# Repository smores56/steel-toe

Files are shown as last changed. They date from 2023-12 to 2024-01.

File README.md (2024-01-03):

The Steel Toe
=============

The Steel Toe is a 34-key split keyboard. It has the following features:

- Choc V1 switches (solder or hotswap)
- Wireless or wired only with any Pro Micro-compatible controller
- Pinky clusters (top pinky keys on the sides)
- Splay (4° between middle and ring, 8° between ring and pinky)
- SplitKB puck support for tenting

<!-- TODO: update pics -->
both sides of PCB

## How to Order

The [gerber ZIP](./pcb/production/gerber.zip) has everything you'll need to get this printed.
You can order from [JLC](https://jlcpcb.com) by just uploading that ZIP archive and keeping
the default options. I'd suggest removing the order number, otherwise they'll put
one on the board somewhere randomly.

## Building

### Parts Needed

Part Name            | Quantity        | Notes                                    | Link
--------------------:|:---------------:|:----------------------------------------:|:----
PCB                  | 2 (halves)      |                                          | Look up hurr hurr
Choc V1 Switches     | 34              |                                          | <https://www.boardsource.xyz/tags/LP_switch>
Choc Hotswaps        | 34              |                                          | <https://www.boardsource.xyz/products/Choc_Hot_Swap_Sockets>
Choc Keycaps         | 34              |                                          | <https://www.boardsource.xyz/tags/LP_keycaps>
Power Switches       | 2               | Technically optional                     | <https://www.boardsource.xyz/products/smd-slide-switch>
Reset Switches       | 2               | Technically optional                     | <https://www.boardsource.xyz/products/reset-switches>
Pro Micro Controller | 2               | Not technically optional                 | <https://www.boardsource.xyz/products/blok>
Small LiPo Batteries | 2               | Technically optional                     | <https://www.boardsource.xyz/products/110mAh_301230r>
MCU Sockets          | 1 strip to chop | Optional                                 | <https://www.boardsource.xyz/products/mill_max_sockets_set>
MCU Socket Pins      | 28              | Optional                                 | <https://www.boardsource.xyz/products/pins>

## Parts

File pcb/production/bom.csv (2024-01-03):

Designator | Footprint | Quantity | Value | LCSC Part #
+1, -1 | single-pin | 2 | MountingHole_Pad
J0 | trrs | 1 | AudioJack4dpb
SW1, SW10, SW11, SW12, SW13, SW14, SW15, SW16, SW17, SW2, SW3, SW4, SW5, SW6, SW7, SW8, SW9 | choc-switch-socket-only | 17 | SW_Push
SW18, SW21 | smd_rst_sw | 2 | SW_Push
SW19, SW20 | power-switch | 2 | SW_SPDT
U1 | ProMicro_facedown_new_dual | 1 | ProMicro_r

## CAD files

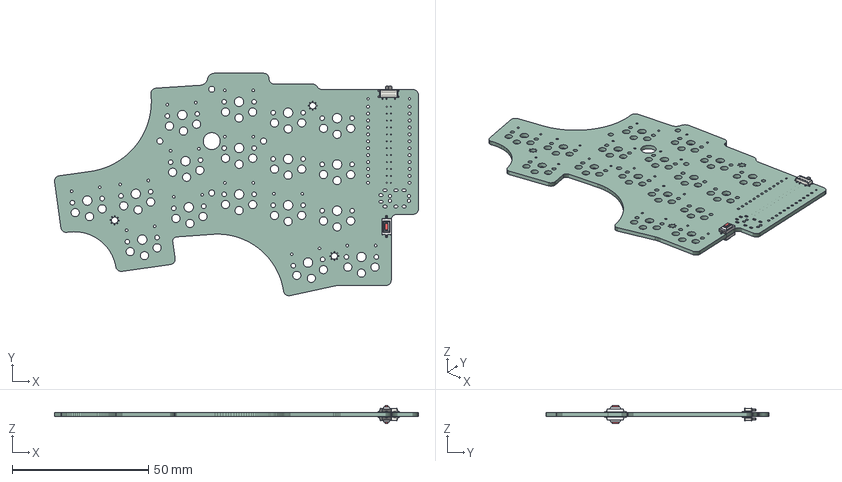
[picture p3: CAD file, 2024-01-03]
pcb/steel-toe.step
133.7 x 81.8 x 6.70 mm
_autosave-steel-toe PCB

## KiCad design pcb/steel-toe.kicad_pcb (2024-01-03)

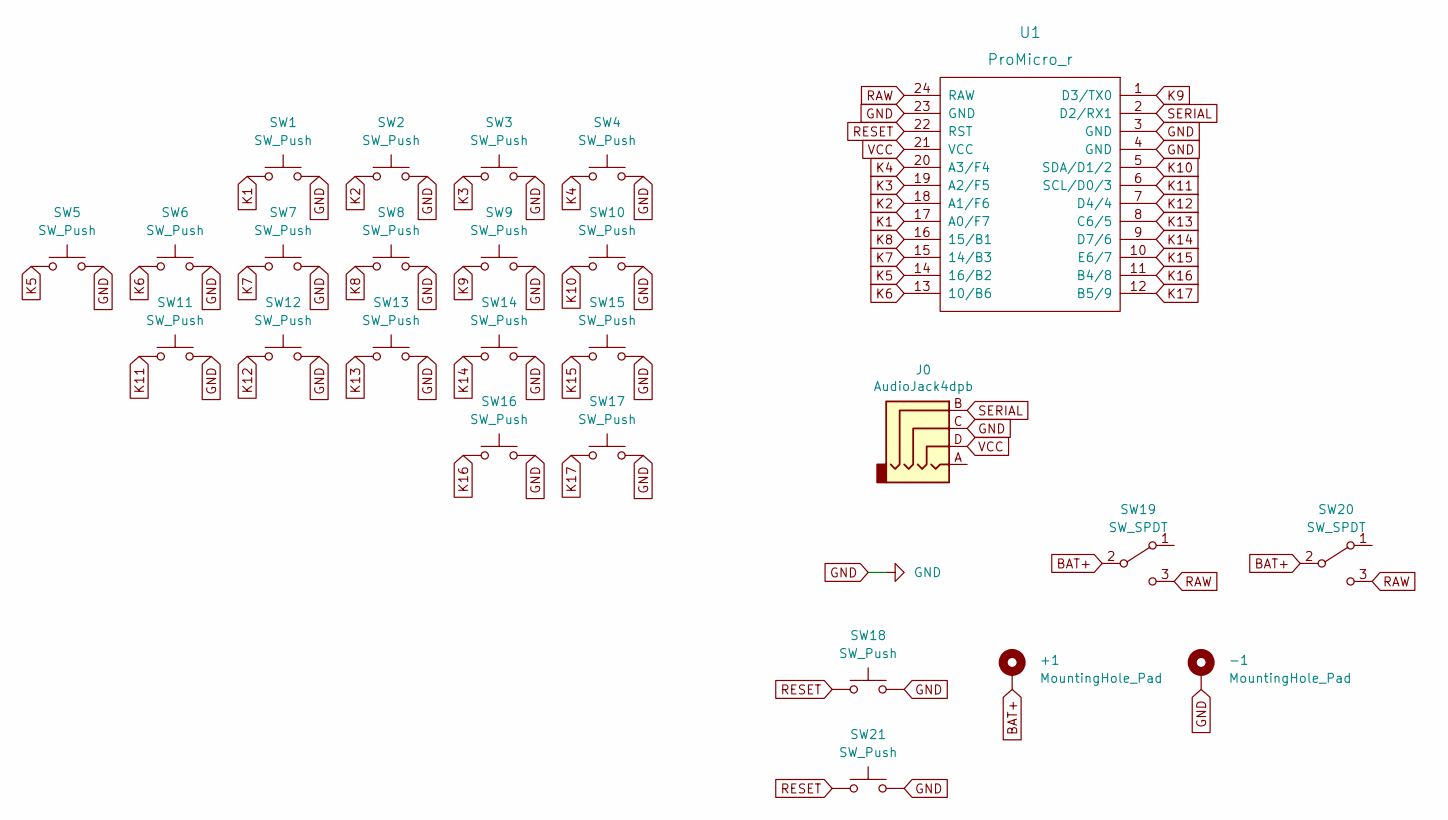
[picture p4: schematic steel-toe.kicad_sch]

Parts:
+1: MountingHole_Pad; single-pin
-1: MountingHole_Pad; single-pin
J0: AudioJack4dpb; trrs
SW1, SW2, SW3, SW4, SW5, SW6, SW7, SW8, SW9, SW10, SW11, SW12, SW13, SW14, SW15, SW16, SW17: SW_Push; choc-switch-socket-only
SW18, SW21: SW_Push; smd_rst_sw
SW19, SW20: SW_SPDT; power-switch
U1: ProMicro_r; ProMicro_facedown_new_dual

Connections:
BAT+: +1.1, SW19.2 (B), SW20.2 (B)
GND: -1.1, J0.C, SW1.2, SW2.2, SW3.2, SW4.2, SW5.2, SW6.2, SW7.2, SW8.2, SW9.2, SW10.2, SW11.2, SW12.2, SW13.2, SW14.2, SW15.2, SW16.2, SW17.2, SW18.2, SW21.2, U1.3 (GND), U1.4 (GND), U1.23 (GND)
K1: SW1.1, U1.17 (A0/F7)
K2: SW2.1, U1.18 (A1/F6)
K3: SW3.1, U1.19 (A2/F5)
K4: SW4.1, U1.20 (A3/F4)
K5: SW5.1, U1.14 (16/B2)
K6: SW6.1, U1.13 (10/B6)
K7: SW7.1, U1.15 (14/B3)
K8: SW8.1, U1.16 (15/B1)
K9: SW9.1, U1.1 (D3/TX0)
K10: SW10.1, U1.5 (SDA/D1/2)
K11: SW11.1, U1.6 (SCL/D0/3)
K12: SW12.1, U1.7 (D4/4)
K13: SW13.1, U1.8 (C6/5)
K14: SW14.1, U1.9 (D7/6)
K15: SW15.1, U1.10 (E6/7)
K16: SW16.1, U1.11 (B4/8)
K17: SW17.1, U1.12 (B5/9)
RAW: SW19.3 (C), SW20.3 (C), U1.24 (RAW)
RESET: SW18.1, SW21.1, U1.22 (RST)
SERIAL: J0.B, U1.2 (D2/RX1)
VCC: J0.D, U1.21 (VCC)

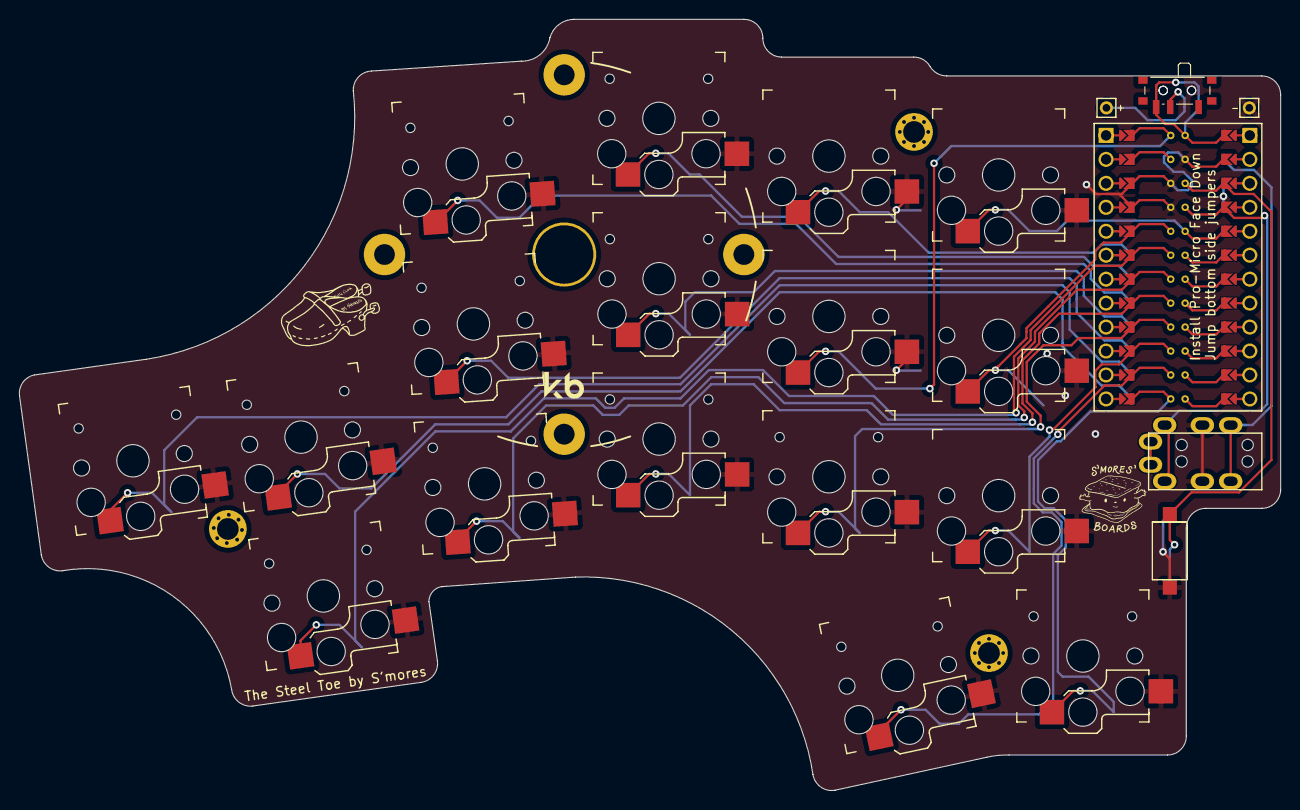
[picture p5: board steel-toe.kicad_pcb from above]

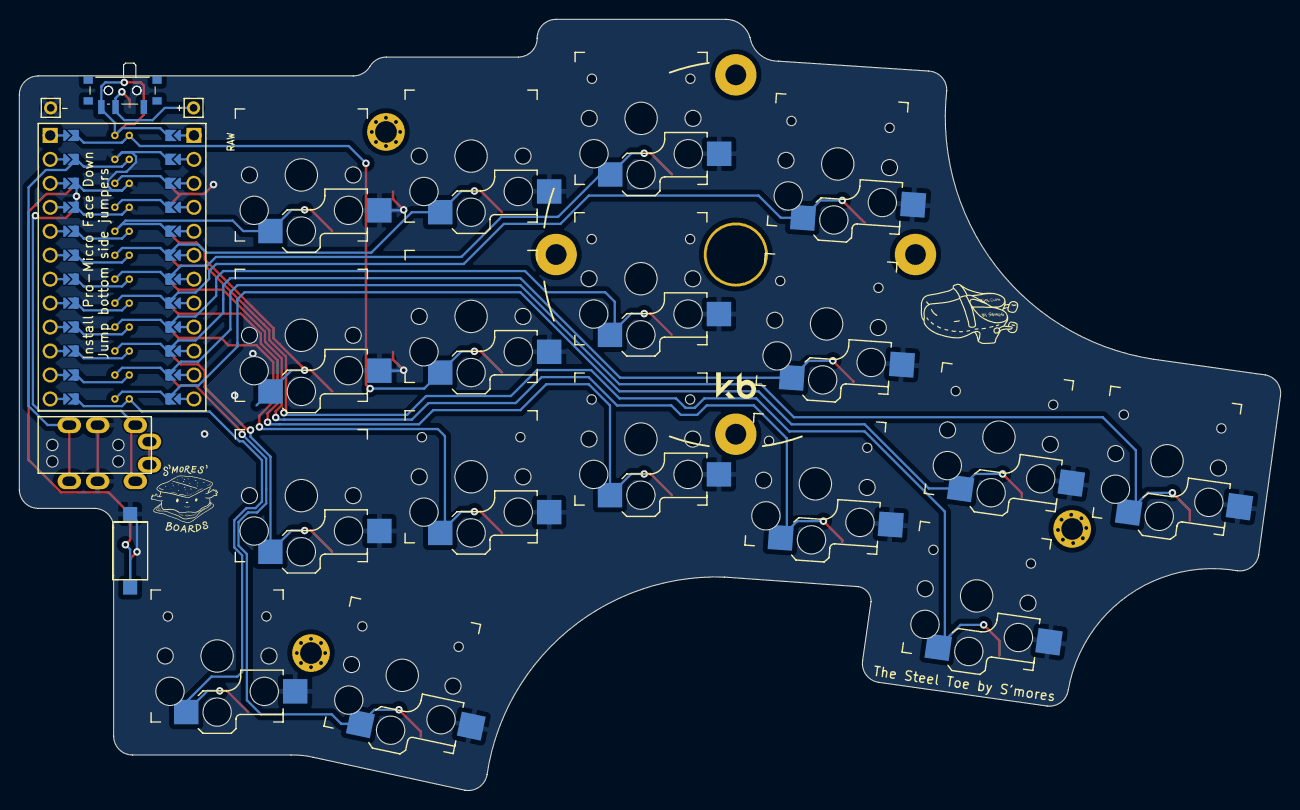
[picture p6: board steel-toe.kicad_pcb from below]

Board: 2 copper layers, 133.7 x 81.8 mm, 28 parts (2 on the bottom side), 23 nets.

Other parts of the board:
Ref**: Val**; m2-hole
Ref**#2, Ref**#3: Val**; m2-hole
